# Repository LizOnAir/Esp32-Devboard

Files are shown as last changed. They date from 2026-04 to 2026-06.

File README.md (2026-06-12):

# ESP32 Devboard

Screenshot 2026-06-12 at 10 23 23 PM

This devboard is created to learn about PCB design rules. I plan to use PCBA for this board.

## Features:
-  battery charging
-  2.4GHz wifi
-  bluetooth

## PCB
Here's my PCB! It was made in KiCad. 
### Schematic
Screenshot 2026-04-14 at 11 25 57 AM

### PCB
Screenshot 2026-04-14 at 11 25 00 AM

## BOM:
Here should be [everything](https://docs.google.com/spreadsheets/d/1wsxLwNynfaC6R5-2-ovum9rVKD0-UjsQx3AUx7Wjfbc/edit?usp=sharing) you need to make this:
- 1x PCBA

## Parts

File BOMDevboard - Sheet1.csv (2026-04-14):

Name | Quantity | Price | Source
PCBA | 1 | $61.90 | https://cart.jlcpcb.com/quote?spm=jlcpcb.Public.2006
Total |  | $61.90

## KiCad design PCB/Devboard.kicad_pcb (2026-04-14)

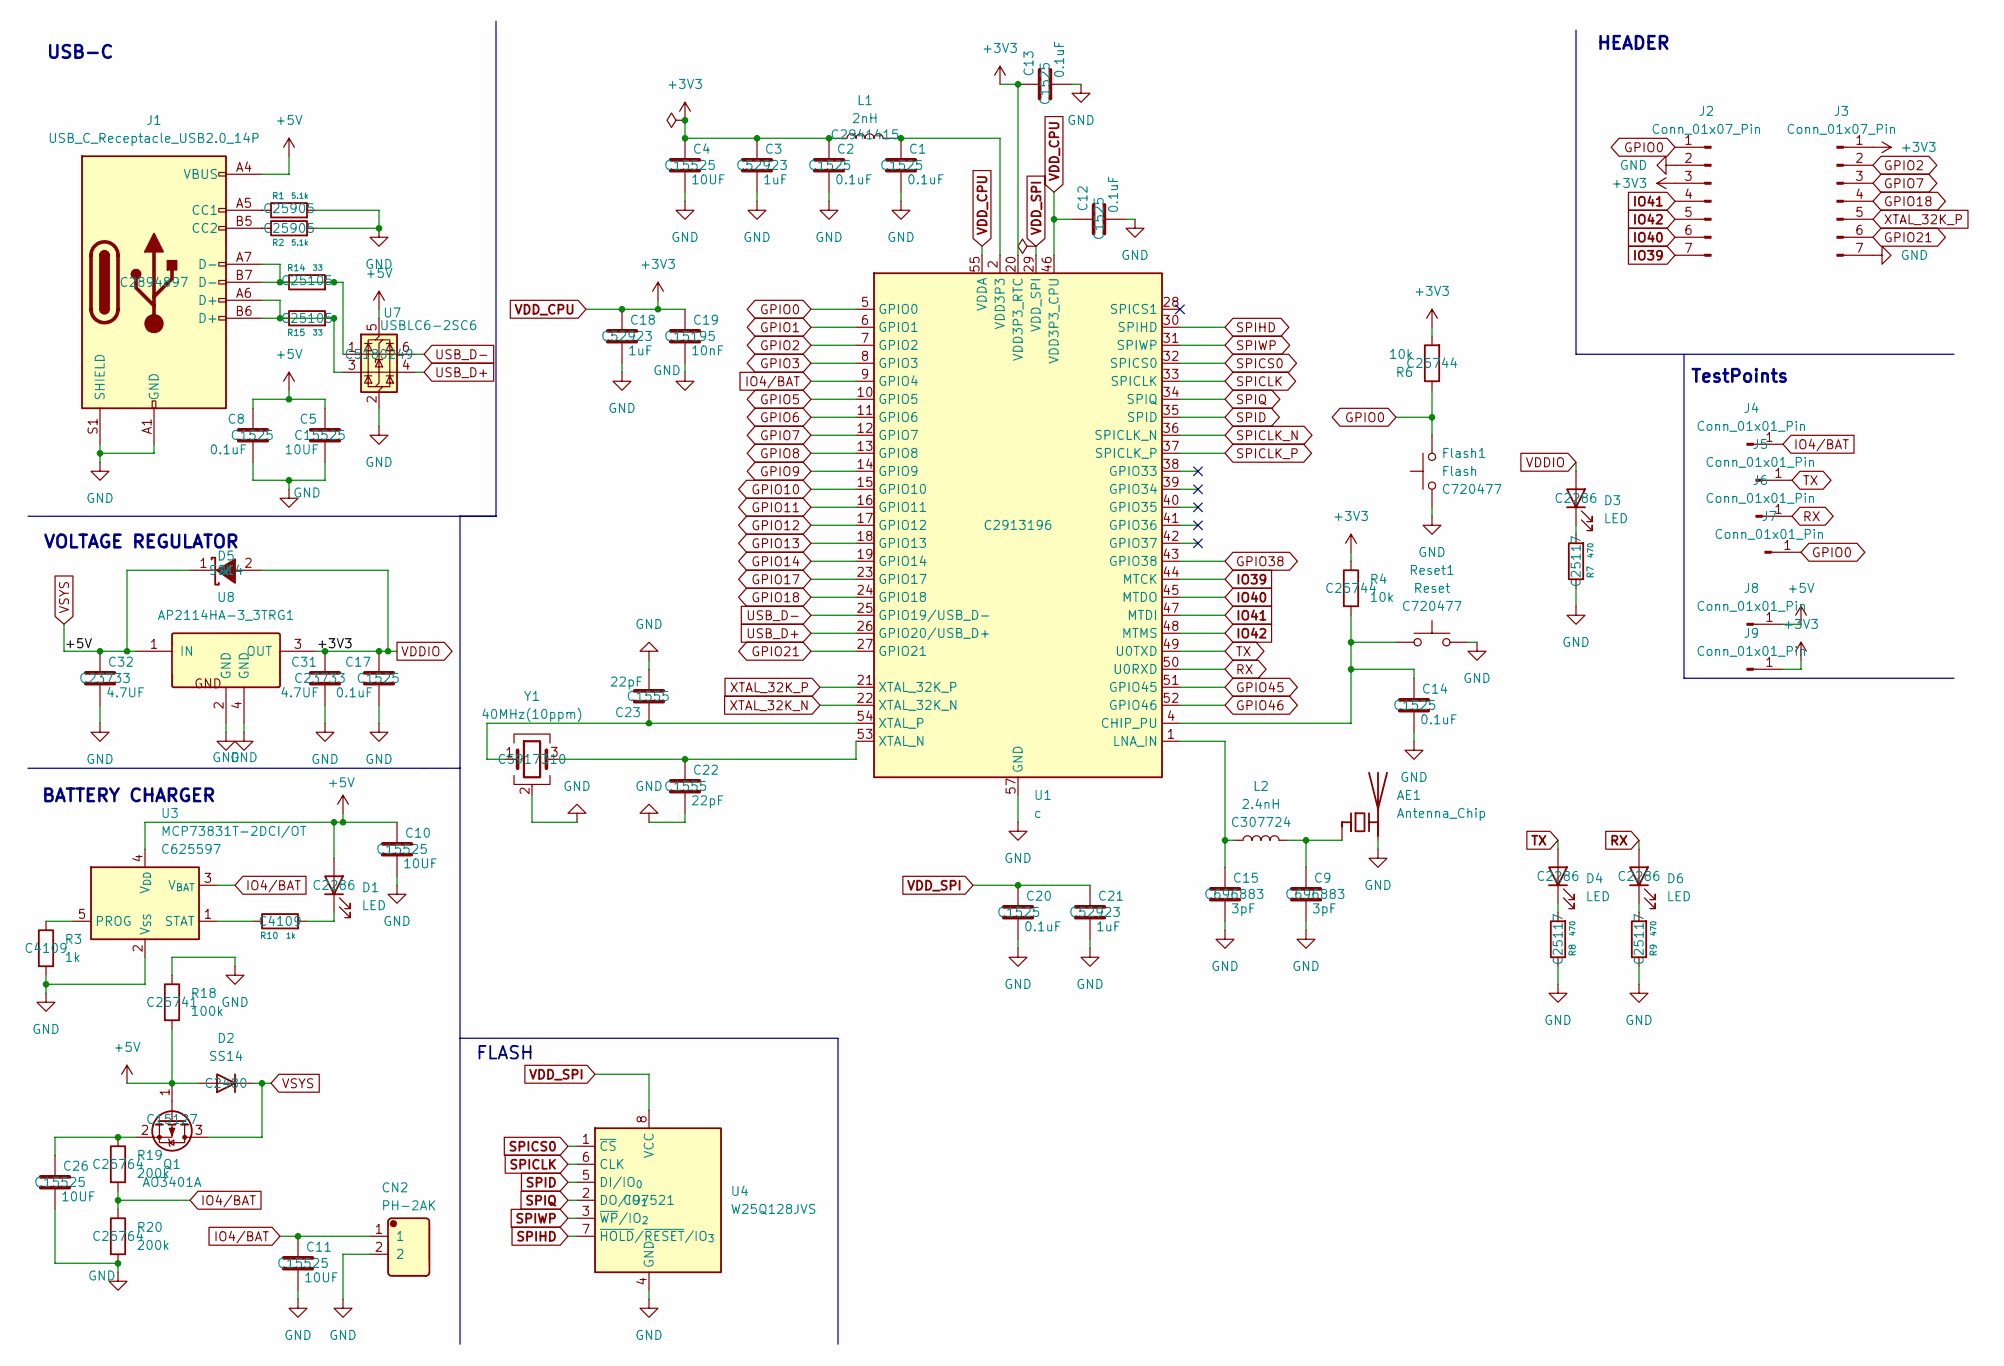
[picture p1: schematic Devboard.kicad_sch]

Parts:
AE1: Antenna_Chip; Texas_SWRA117D_2.4GHz_Left
C1, C2, C8, C12, C13, C14, C17, C20: 0.1uF; C_0402_1005Metric; MNF part num C1525
C3, C18, C21: 1uF; C_0402_1005Metric; MNF part num C52923
C4, C5, C10, C11, C26: 10UF; C_0402_1005Metric; MNF part num C15525
C9, C15: 3pF; C_0402_1005Metric; MNF part num C696883
C19: 10nF; C_0402_1005Metric; MNF part num C15195
C22, C23: 22pF; C_0402_1005Metric; MNF part num C1555
C31, C32: 4.7UF; C_0402_1005Metric; MNF part num C23733
CN2: PH-2AK; JST_PH_S2B-PH-K_1x02_P2.00mm_Horizontal; Manufacturer Part PH-2AK; LCSC C8886
D1, D3, D4, D6: LED; LED_0603_1608Metric; MNF part num C2286
D2: SS14; D_SMA; MNF part num C2480
D5: SS14; Manufacturer Part SS14; LCSC C2480
Flash1: Flash; SW_TS-1088-AR02016; MNF part num C720477
J1: USB_C_Receptacle_USB2.0_14P; USB_C_Receptacle_HCTL_HC-TYPE-C-16P-01A; MNF part num C2894897
J2, J3: Conn_01x07_Pin; PinHeader_1x07_P1.00mm_Vertical
J4, J5, J6, J7, J8, J9: Conn_01x01_Pin; TestPoint_Pad_D1.0mm
L1: 2nH; L_0402_1005Metric_Pad0.77x0.64mm_HandSolder; MNF part num C2941415
L2: 2.4nH; L_0402; MNF part num C307724
Q1: AO3401A; SOT-23; MNF part num C15127
R1, R2: 5.1k; R_0402; MNF part num C25905
R3, R10: 1k; R_0402; MNF part num C4109
R4, R6: 10k; R_0402_1005Metric; MNF part num C25744
R7, R8, R9: 470; R_0402; MNF part num C25117
R14, R15: 33; R_0402; MNF part num C25105
R18: 100k; R_0402; MNF part num C25741
R19, R20: 200k; R_0402; MNF part num C25764
Reset1: Reset; SW_TS-1088-AR02016; MNF part num C720477
U1: c; QFN-56-1EP_7x7mm_P0.4mm_EP4x4mm; MNF part num C2913196
U3: MCP73831T-2DCI/OT; SOT-23-5; MNF part num C625597
U4: W25Q128JVS; SOIC-8_5.3x5.3mm_P1.27mm; MNF part num C97521
U7: USBLC6-2SC6; SOT-23-6; MNF part num C5180249
U8: AP2114HA-3_3TRG1; Manufacturer Part AP2114HA-3.3TRG1; LCSC C460314
Y1: 40MHz(10ppm); Crystal_SMD_2520-4Pin_2.5x2.0mm; MNF part num C5917310

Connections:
GND: AE1.2 (PCB_Trace), C1.2, C2.2, C3.2, C4.2, C5.2, C8.2, C9.2, C10.2, C11.2, C12.2, C13.2, C14.2, C15.2, C17.2, C18.2, C19.2, C20.2, C21.2, C22.2, C23.2, C26.2, C31.2, C32.2, CN2.2, Flash1.1, J1.A1 (GND), J1.A12 (GND), J1.B1 (GND), J1.B12 (GND), J1.S1 (SHIELD), J2.2, J3.7, R1.2, R2.2, R3.2, R7.1, R8.1, R9.1, R18.1, R20.2, Reset1.2, U1.57 (GND), U3.2 (V_{SS}), U4.4 (GND), U7.2 (GND), U8.2 (GND), U8.4 (GND), Y1.2 (G), Y1.4 (G)
GPIO0: Flash1.2, J2.1, J7.1, R6.1, U1.5 (GPIO0)
GPIO1: U1.6 (GPIO1)
GPIO2: J3.2, U1.7 (GPIO2)
GPIO3: U1.8 (GPIO3)
GPIO5: U1.10 (GPIO5)
GPIO6: U1.11 (GPIO6)
GPIO7: J3.3, U1.12 (GPIO7)
GPIO8: U1.13 (GPIO8)
GPIO9: U1.14 (GPIO9)
GPIO10: U1.15 (GPIO10)
GPIO11: U1.16 (GPIO11)
GPIO12: U1.17 (GPIO12)
GPIO13: U1.18 (GPIO13)
GPIO14: U1.19 (GPIO14)
GPIO17: U1.23 (GPIO17)
GPIO18: J3.4, U1.24 (GPIO18)
GPIO21: J3.6, U1.27 (GPIO21)
GPIO38: U1.43 (GPIO38)
GPIO45: U1.51 (GPIO45)
GPIO46: U1.52 (GPIO46)
IO4/BAT: C11.1, CN2.1, J4.1, R19.2, R20.1, U1.9 (GPIO4), U3.3 (V_{BAT})
IO39: J2.7, U1.44 (MTCK)
IO40: J2.6, U1.45 (MTDO)
IO41: J2.4, U1.47 (MTDI)
IO42: J2.5, U1.48 (MTMS)
unnamed: AE1.1 (FEED), C9.1, L2.2
unnamed: C1.1, L1.2, U1.2 (VDD3P3), U1.3 (VDD3P3)
unnamed: D1.1 (K), R10.2
unnamed: D3.1 (K), R7.2
unnamed: D4.1 (K), R8.2
unnamed: D6.1 (K), R9.2
unnamed: J1.A5 (CC1), R1.1
unnamed: J1.B5 (CC2), R2.1
unnamed: J1.A6 (D+), J1.B6 (D+), R15.1, R15.2, U7.3 (I/O2)
unnamed: J1.A7 (D-), J1.B7 (D-), R14.1, R14.2, U7.1 (I/O1)
unnamed: C26.1, Q1.2 (S), R19.1
unnamed: C14.1, R4.2, Reset1.1, U1.4 (CHIP_PU)
unnamed: C15.1, L2.1, U1.1 (LNA_IN)
unnamed: C22.1, U1.53 (XTAL_N), Y1.3
unnamed: C23.1, U1.54 (XTAL_P), Y1.1
unnamed: R3.1, U3.5 (PROG)
unnamed: R10.1, U3.1 (STAT)
RX: D6.2 (A), J6.1, U1.50 (U0RXD)
SPICLK: U1.33 (SPICLK), U4.6 (CLK)
SPICLK_N: U1.36 (SPICLK_N)
SPICLK_P: U1.37 (SPICLK_P)
SPICS0: U1.32 (SPICS0), U4.1 (~CS)
SPID: U1.35 (SPID), U4.5 (DI/IO_{0})
SPIHD: U1.30 (SPIHD), U4.7 (~HOLD/~RESET/IO_{3})
SPIQ: U1.34 (SPIQ), U4.2 (DO/IO_{1})
SPIWP: U1.31 (SPIWP), U4.3 (~WP/IO_{2})
TX: D4.2 (A), J5.1, U1.49 (U0TXD)
USB_D+: U1.26 (GPIO20/USB_D+), U7.4 (I/O2)
USB_D-: U1.25 (GPIO19/USB_D-), U7.6 (I/O1)
VDDIO: C2.1, C3.1, C4.1, C12.1, C13.1, C17.1, C18.1, C19.1, C31.1, D3.2 (A), D5.2 (A), J2.3, J3.1, J9.1, L1.1, R4.1, R6.2, U1.20 (VDD3P3_RTC), U1.46 (VDD3P3_CPU), U1.55 (VDDA), U1.56 (VDDA), U8.3 (OUT)
VDD_SPI: C20.1, C21.1, U1.29 (VDD_SPI), U4.8 (VCC)
VSYS: C5.1, C8.1, C10.1, C32.1, D1.2 (A), D2.1 (K), D2.2 (A), D5.1 (K), J1.A4 (VBUS), J1.A9 (VBUS), J1.B4 (VBUS), J1.B9 (VBUS), J8.1, Q1.1 (G), Q1.3 (D), R18.2, U3.4 (V_{DD}), U7.5 (VBUS), U8.1 (IN)
XTAL_32K_N: U1.22 (XTAL_32K_N)
XTAL_32K_P: J3.5, U1.21 (XTAL_32K_P)

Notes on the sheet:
FLASH
BATTERY CHARGER
HEADER
VOLTAGE REGULATOR
USB-C
TestPoints

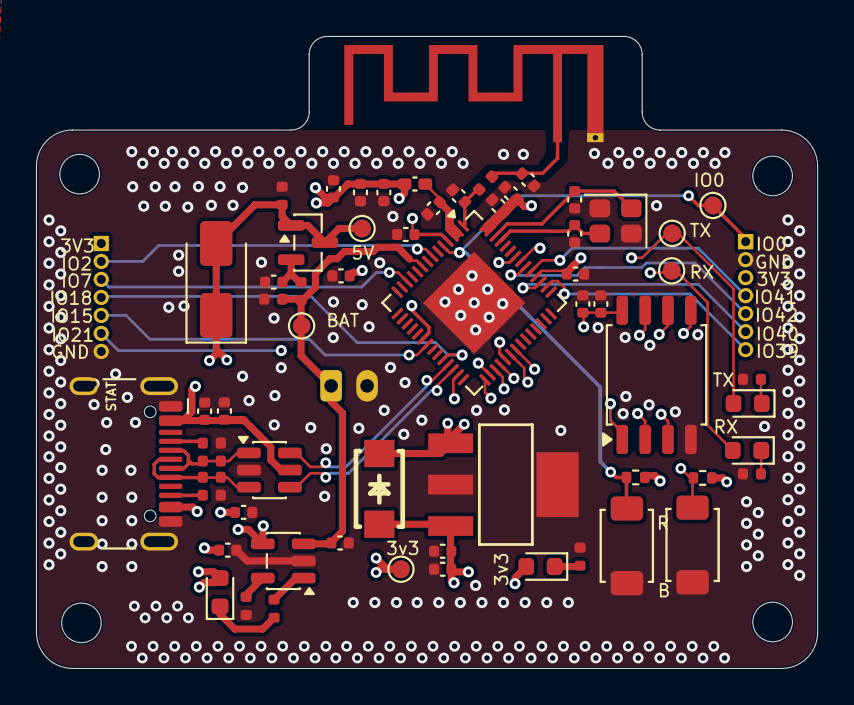
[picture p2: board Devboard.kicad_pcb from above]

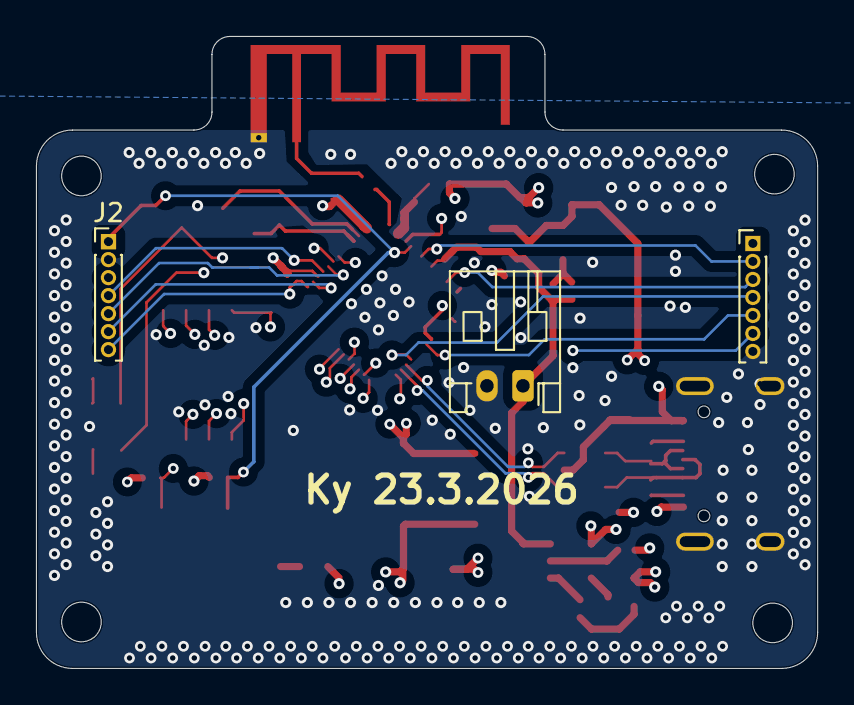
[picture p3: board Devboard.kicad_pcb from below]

Board: 4 copper layers, 43.4 x 35.1 mm, 65 parts (3 on the bottom side), 42 nets.
